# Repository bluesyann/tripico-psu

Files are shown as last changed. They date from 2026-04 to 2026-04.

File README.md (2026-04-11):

<p align="center">
	TriPico PSU Logo
</p>

<h1 align="center">TriPico PSU</h1>

<p align="center">
	
	
	
	
</p>

<p align="center">
	
	
	
</p>

> A 3-channel Raspberry Pi Pico instrument that works as a programmable power supply, bench voltmeter/ammeter, and YAML-driven curve tracer all in one.

---

## ⚡ What Is This?

TriPico PSU is a 3-channel instrument built around a Raspberry Pi Pico and dual INA3221 measurement ICs. It can be configured as:

- **Programmable multi-channel power supply** — independent voltage/current regulation on 3 channels with max power limits
- **Live voltmeter/ammeter front end** — real-time monitoring with interactive desktop GUI and live charts
- **Curve tracer** — automated characterization of transistors, diodes, and components using YAML recipe automation

### Repository Structure

- **[hardware/README.md](hardware/README.md)** — PCB schematic, PCB layout, front-panel design, and wiring integration
- **[firmware/README.md](firmware/README.md)** — Raspberry Pi Pico firmware (MicroPython async control loop)
- **[software/README.md](software/README.md)** — Host computer application (interactive GUI + YAML automation)

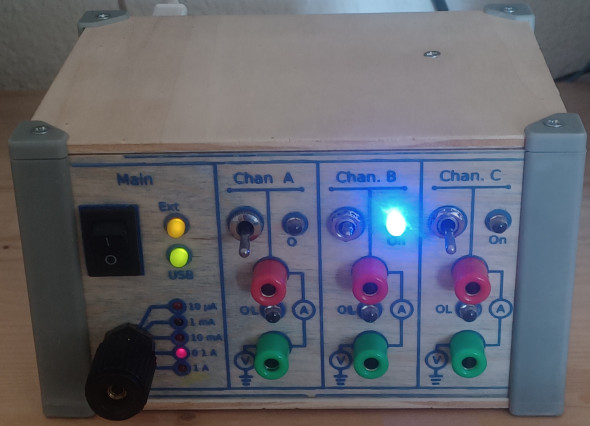
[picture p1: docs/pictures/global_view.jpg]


### Picture Insertion Block: Full Build Overview

Use this block when you have a cleaner hero photo than global_view.jpg.

```md
![TriPico PSU - complete build](docs/pictures/overview_complete_build.jpg)
```

---

## 🎯 How It Works

The Pico firmware regulates 3 channels independently, continuously reads voltage/current through dual INA3221 sensors, and streams measurements over serial at 115200 baud. On the computer side, you have two modes:

- **Interactive GUI mode** — real-time control and monitoring with live voltage/current charts
- **YAML automation mode** — scripted sweeps, static test runs, CSV export, and optional plots

---

## 🚀 Build And Run (Step By Step)

### 1) Build The Hardware

### Picture Insertion Block: Build Steps Collage

Add one image showing PCB + panel + enclosure parts before assembly.

```md
![Hardware build steps](docs/pictures/build_steps_collage.jpg)
```

1. Open the KiCad files and fabricate/assemble the PCB.
2. Build the front panel/enclosure from the provided enclosure assets.
3. Wire the panel elements (switches, relays, connectors, LEDs) to the PCB.

Detailed files and notes are in [hardware/README.md](hardware/README.md).

### 2) Flash The Pico Firmware

### Picture Insertion Block: Pico Flashing

Show your firmware upload workflow or MicroPython file layout.

```md
![Firmware flashing workflow](docs/pictures/pico_firmware_upload.jpg)
```

1. Copy all files from the firmware folder to the Pico:
	 - config.py
	 - device.py
	 - ina3221.py
	 - main.py
2. Reboot the board and verify serial output appears.

Firmware details are in [firmware/README.md](firmware/README.md).

### 3) Set Up The Computer Software

### Picture Insertion Block: Software Setup

Optional terminal screenshot after successful dependency install.

```md
![Host software setup](docs/pictures/software_setup_terminal.jpg)
```

1. Create a Python virtual environment.
2. Install dependencies from software/requirements.txt.
3. Configure software/tripico-psu_config.yaml for your serial port and calibration folder.

Software details are in [software/README.md](software/README.md).

### 4) Use It

### Picture Insertion Block: First Run

Add one screenshot with the GUI connected and channels active.

```md
![First successful run](docs/pictures/first_run_connected_gui.jpg)
```

- GUI mode (interactive bench use):
	- Run software/tripico-psu_gui.py
	- Connect to the Pico
	- Set channel mode (V or mA), setpoint, and max power

- YAML mode (automation and characterization):
	- Run software/tripico-psu_run_yaml.py with one YAML recipe from software/examples
	- Capture sweeps/static runs to CSV and optional plots

---

## 📊 Typical Practical Uses

### Standalone power supply behavior

### Picture Insertion Block: Power Supply Mode

```md
![Power supply mode example](docs/pictures/mode_power_supply.jpg)
```

- Set channels in voltage or current mode
- Apply max-power protection per channel
- Monitor live values and status (regulation/saturation/alerts)

### Digital voltmeter/ammeter style usage

### Picture Insertion Block: Meter Mode

```md
![Voltmeter ammeter mode example](docs/pictures/mode_meter.jpg)
```

- Use one or more channels as sensing points
- Observe time-series voltage/current in the GUI
- Switch measurement range from the front panel selector

### Curve tracer usage

### Picture Insertion Block: Curve Tracer Plot

```md
![Curve tracer example plot](docs/pictures/mode_curve_tracer_plot.jpg)
```

- Define nested sweeps in YAML (for example transistor curves)
- Plot I-V behavior in real time
- Export data for offline analysis

## Example Screens

- GUI examples:
	- [docs/pictures/gui.png](docs/pictures/gui.png)
	- [docs/pictures/gui2.png](docs/pictures/gui2.png)

## Current Status

This repository already contains working code and build assets. Hardware assembly details are intentionally partial and should be completed with your own wiring/BOM documentation as you finalize your build.

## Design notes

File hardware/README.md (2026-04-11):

<p align="center">
  TriPico Hardware Logo
</p>

<h1 align="center">Hardware Build Guide</h1>
<p align="center"><strong>PCB + Front Panel + Wiring Integration</strong></p>

<p align="center">
  
  
  
</p>

# 🏗️ Hardware Build Guide

> PCB design, front-panel enclosure, mechanical integration, and electrical bring-up.

This guide covers the complete hardware design and assembly workflow:

## Picture Insertion Block: Hardware Assembly Overview

```md
![Hardware assembly overview](../docs/pictures/hw_overview_assembly.jpg)
```

- **KiCad project** (complete schematic + PCB layout)
- **Front panel enclosure files** (SVG vector artwork + OpenSCAD 3D extrusion script)

This guide is intentionally conservative where assembly details depend on your specific choices (connectors, wiring gauge, fuse ratings, etc.).

## 📋 What Is In This Folder

## Picture Insertion Block: Repository Hardware Assets

```md
![Hardware files map](../docs/pictures/hw_repo_assets_map.jpg)
```

- kicad/
  - tripico-psu.kicad_sch: electrical schematic
  - tripico-psu.kicad_pcb: PCB layout
  - tripico-psu.kicad_pro and tripico-psu.kicad_prl: project settings

- enclosure/
  - front_panel_inkscape.svg: editable panel design
  - front_panel_polygon.svg: panel path used for extrusion
  - front_panel.scad: OpenSCAD extrusion script

## 🎯 Suggested Physical Architecture

## Picture Insertion Block: Front Panel Layout

```md
![Front panel layout](../docs/pictures/hw_front_panel_layout.jpg)
```

Based on the files and pictures, the build appears to include:

- A main PCB with one Raspberry Pi Pico and analog/power stages
- Front-panel controls and indicators:
  - Main power switch
  - Range selector for current measurement shunts
  - Push-pull channel enable switches (A/B/C)
  - Channel output terminals
  - Status LEDs and safety indication
- External supply input connector

Use the schematic and PCB net labels as the source of truth for wiring.

## 🔨 Build Workflow

### 1) PCB Fabrication And Assembly

### Picture Insertion Block: PCB Render And Assembled Board

```md
![PCB render and assembled board](../docs/pictures/hw_pcb_render_and_real_board.jpg)
```

1. Open kicad/tripico-psu.kicad_pro in KiCad.
2. Run ERC/DRC and inspect any warnings before fabrication.
3. Generate Gerbers and drill files from the PCB editor.
4. Assemble components according to the schematic and footprints.

### 2) Front Panel Fabrication

### Picture Insertion Block: Panel Fabrication

```md
![Panel fabrication process](../docs/pictures/hw_panel_fabrication_steps.jpg)
```

1. Edit enclosure/front_panel_inkscape.svg for labels/hole placement.
2. Use enclosure/front_panel_polygon.svg with OpenSCAD:

```scad
linear_extrude(height = 0.5) import("front_panel_polygon.svg");
```

3. Export for your process (laser/CNC/print) as needed.

### 3) Mechanical Integration

### Picture Insertion Block: Internal Wiring

```md
![Internal wiring and mounting](../docs/pictures/hw_internal_wiring.jpg)
```

1. Mount PCB in enclosure.
2. Mount panel hardware (switches, jacks, LEDs).
3. Route and secure wiring between panel and PCB connectors.

### 4) Electrical Bring-Up

### Picture Insertion Block: Bring-Up Checklist Bench Setup

```md
![Electrical bring up bench setup](../docs/pictures/hw_bringup_bench_setup.jpg)
```

1. Perform continuity checks before power-on.
2. Bring up with current-limited bench supply first.
3. Verify rails, relay behavior, and panel switch detection.
4. Flash firmware and test serial communication with host software.

## ✅ Wiring Checklist (To Complete)

## Picture Insertion Block: Final Wiring Diagram

```md
![Final wiring diagram](../docs/pictures/hw_final_wiring_diagram.jpg)
```

Use this section as your own integration checklist:

- External power input connector pinout: TODO
- Output terminal mapping for channels A/B/C: TODO
- Panel LED wiring and polarity: TODO
- Push-pull switch wiring reference: TODO
- Range selector switch wiring reference: TODO
- Safety relay coil and contact wiring: TODO
- Fuse/protection devices and ratings: TODO

## ⚠️ Safety Notes

- Use an inline fuse on the external supply input.
- Keep high-current traces/wires short and appropriately sized.
- Verify grounding strategy between analog sensing and power paths.
- Confirm enclosure insulation and strain relief before regular use.

## Assets For Documentation

Project image: docs/pictures/global_view.jpg

You can extend this README with BOM, exact connector references, and final wiring photos as you finalize your hardware revision.

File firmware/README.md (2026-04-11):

<p align="center">
  TriPico Firmware Logo
</p>

<h1 align="center">Firmware Guide</h1>
<p align="center"><strong>Raspberry Pi Pico + MicroPython</strong></p>

<p align="center">
  
  
  
</p>

# 🔧 Firmware (Raspberry Pi Pico / MicroPython)

> Complete control loop and measurement streaming for the Raspberry Pi Pico board.

This firmware orchestrates the core device behavior: 3-channel regulation, continuous measurement through INA3221 sensors, safety relay management, and serial communication with the host computer.

## Picture Insertion Block: Firmware Context

```md
![Pico firmware context](../docs/pictures/fw_pico_board_context.jpg)
```

Specifically, it handles:

- 3-channel regulation (voltage or current mode)
- Voltage/current measurements through INA3221 devices
- Safety relay management
- Front-panel switch monitoring
- Serial communication with the host computer

## 📋 Files Overview

- main.py
  - Async entry point and task orchestration
  - Serial RX/TX, regulation loops, state reporting, safety logic

- device.py
  - Hardware initialization (I2C, INA3221, PWM, GPIO, UART)
  - Exposes initialized peripheral objects used by main.py

- config.py
  - Pin mapping and constants
  - PWM settings, range mapping, current limits, safety thresholds

- ina3221.py
  - INA3221 MicroPython driver used for bus voltage and shunt current readings

## 🔌 Hardware Mapping (From Firmware Perspective)

## Picture Insertion Block: Firmware Pinout

```md
![Pico pin mapping used by firmware](../docs/pictures/fw_gpio_mapping_diagram.jpg)
```

- PWM outputs: GPIO 18/17/16 (channels A/B/C)
- INA3221 high-current device on I2C0 (GPIO 8/9)
- INA3221 low-current device on I2C1 (GPIO 2/3)
- Range selector inputs: GPIO 10..14
- Push-pull switch inputs: GPIO 19/20/21
- Safety relays outputs: GPIO 26/27/28
- Safety relay re-enable button: GPIO 22
- UART1 serial: TX GPIO 4, RX GPIO 5

## 🔄 Runtime Architecture

## Picture Insertion Block: Async Task Diagram

```md
![Firmware async task flow](../docs/pictures/fw_async_tasks_flow.jpg)
```

The runtime consists of independent asynchronous tasks that work in parallel without blocking:

- watch_user_panel_state: reads range selector and push-pull switches
- serial_read: parses host commands
- serial_write: sends periodic measurements
- regulator (one per channel): closes control loop
- send_channels_state: emits saturation/regulation states
- safety_relays_control: enforces limits and handles reset button

Each channel dictionary stores setpoints, measurements, state, and hardware references.

## 📡 Host Command Protocol

## Picture Insertion Block: Serial Protocol Cheat Sheet

```md
![Firmware serial command cheat sheet](../docs/pictures/fw_serial_commands_cheatsheet.jpg)
```

The firmware parses line-based commands and supports:

- set sampling <Hz>
- set voffset <V>
- SAFETY RELAYS <0|1>
- USER PANEL STATE
- <channel> v
- <channel> i
- <channel> nc
- <channel> <value>
- <channel> <max_power>w

Where <channel> is a, b, or c.

## Data Stream Format

## Picture Insertion Block: Sample Serial Capture

```md
![Serial data stream capture](../docs/pictures/fw_serial_stream_capture.jpg)
```

The firmware periodically sends one line with:

- elapsed_time_s
- per channel: name i_measured_mA v_measured_V setpoint

Example shape:

```text
12.340 a 5.1 3.30 3.30 b 0.2 1.80 2.00 c 0.0 0.00 0.00
```

Additional event lines are emitted for:

- Range changes
- Channel regulation/saturation state
- Alert conditions
- Push-pull switch changes

## Safety Logic

## Picture Insertion Block: Safety Events

```md
![Safety relay and alert behavior](../docs/pictures/fw_safety_relays_alerts.jpg)
```

Safety relay control checks:

- Max voltage (MAX_VOLTAGE)
- Max current per selected range (MAX_CURRENTS)
- Per-channel max power (from host command)

On violation, relay opens and an Alert event is sent to host.

## Deploy To Pico

## Picture Insertion Block: File Layout On Pico

```md
![Files copied to Pico root](../docs/pictures/fw_files_on_pico_root.jpg)
```

Copy these files to the Pico filesystem root:

- config.py
- device.py
- ina3221.py
- main.py

Then reset the board. main.py starts automatically.

## Tuning Notes

- PID_DT and gain terms in main.py affect regulation stability.
- PWM_FREQ and MAX_PWM_INCREMENT in config.py affect response and smoothness.
- Range selector logic assumes exactly one active (grounded) range pin.

## Debugging Tips

- Open serial logs to verify command parsing and state transitions.
- Check range selector inputs if current reads as None.
- Confirm INA3221 wiring/addressing if channels stop reporting.

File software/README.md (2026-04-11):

<p align="center">
  TriPico Software Logo
</p>

<h1 align="center">Software Guide</h1>
<p align="center"><strong>Host PC Application (GUI + YAML Automation)</strong></p>

<p align="center">
  
  
  
</p>

# 💻 Software (Host Computer)

> Interactive GUI and YAML automation runner that connects over serial to the Pico firmware.

This software provides two complementary modes for interacting with the hardware:

## Picture Insertion Block: Software Overview

```md
![Host software overview](../docs/pictures/sw_overview_gui_and_yaml.jpg)
```

**Two Operating Modes**:

- Interactive GUI mode via tripico-psu_gui.py
- YAML automation mode via tripico-psu_run_yaml.py

## 📚 Files Overview

- tripico-psu_gui.py
	- Desktop GUI for live monitoring and manual channel control
	- Connects over serial to the Pico firmware
	- Displays real-time voltage/current charts and channel states

- tripico-psu_run_yaml.py
	- CLI runner for scripted characterization workflows
	- Validates YAML inputs against validation_schema.yaml
	- Executes sweeps/static runs, writes CSV, optionally saves plots

- serial_functions.py
	- Serial protocol helpers (send commands, parse incoming data)
	- Sweep engine and panel-state checks

- calib_functions.py
	- Loads and applies calibration offsets/gains from external files

- tripico-psu_config.yaml
	- Global host settings (channels, serial device pattern, GUI config, calibration path)

- validation_schema.yaml
	- YAML schema for characterization recipe validation

- examples/
	- Example characterization files for transistor and source testing

## 🐍 Python Environment Setup

## Picture Insertion Block: Dependency Install

```md
![Python environment and dependency install](../docs/pictures/sw_install_dependencies_terminal.jpg)
```

From this folder:

```bash
python -m venv venv
venv\\Scripts\\activate
pip install -r requirements.txt
```

On Linux/macOS:

```bash
python3 -m venv venv
source venv/bin/activate
pip install -r requirements.txt
```

## ⚙️ Configuration

## Picture Insertion Block: Config File Example

```md
![tripico-psu_config.yaml annotated example](../docs/pictures/sw_config_yaml_example.jpg)
```

Edit tripico-psu_config.yaml before running:

- setup.channels: active channels (typically a, b, c)
- setup.device: serial device glob
	- Linux example: /dev/ttyACM*
	- Windows example: COM3
- setup.calibration_folder: path to calibration files
- gui.*: GUI size/colors/sampling/time-window defaults

## 🖥️ Run The GUI (Interactive Mode)

## Picture Insertion Block: GUI Main Window

You can use one of the existing screenshots first, then replace with your own later.

```md
![GUI screenshot](../docs/pictures/gui.png)
```

```bash
python tripico-psu_gui.py
```

Workflow:

1. Select serial port and baudrate.
2. Click Connect.
3. Per channel, set value/unit/max power and click Update.
4. Watch live charts and status fields.

Expected channel status messages include:

- PID Regulation
- Saturation High / Saturation Low
- Alert and push-pull connection state changes

## Picture Insertion Block: GUI Status States

```md
![GUI channel states example](../docs/pictures/sw_gui_channel_states.jpg)
```

## 📈 Run YAML Characterization (Automation Mode)

## Picture Insertion Block: YAML Runner In Terminal

```md
![YAML run from terminal](../docs/pictures/sw_yaml_run_terminal.jpg)
```

```bash
python tripico-psu_run_yaml.py examples/npn_output_characteristics.yaml -device /dev/ttyACM0 -baud 115200
```

Useful options:

- -d / --debug: verbose logging
- --no-prompt: do not wait for Enter between characterizations

The runner will:

1. Load tripico-psu_config.yaml.
2. Validate the input YAML against validation_schema.yaml.
3. Ensure panel/range state is ready.
4. Initialize channels on the Pico.
5. Run sweep/static sequence.
6. Save output CSV when datafile is defined.

## YAML Recipe Structure (Quick Reference)

## Picture Insertion Block: YAML Recipe Annotated

```md
![Annotated characterization YAML](../docs/pictures/sw_yaml_recipe_annotated.jpg)
```

Main keys:

- comment
- caracs: list of characterizations

Per characterization:

- name
- init:
	- range
	- voffset
	- sampling
	- channels: Name, control, initvalue, max_power
- either static or sweep
- optional plots
- optional datafile

Nested sweeps are supported with sweep.sweep for curve tracing.

## Serial Link Expectations

## Picture Insertion Block: Parsed Data And Events

```md
![Data and event parsing overview](../docs/pictures/sw_serial_data_and_events.jpg)
```

- Default baudrate: 115200
- The host expects periodic samples in one line containing timestamp + all channels
- Events (range changes, alerts, state changes) are parsed separately

## Notes

- The software is tightly coupled to firmware command names and channel fields.
- If you rename YAML keys or channel dictionary fields, update GUI/runner/serial helpers together.

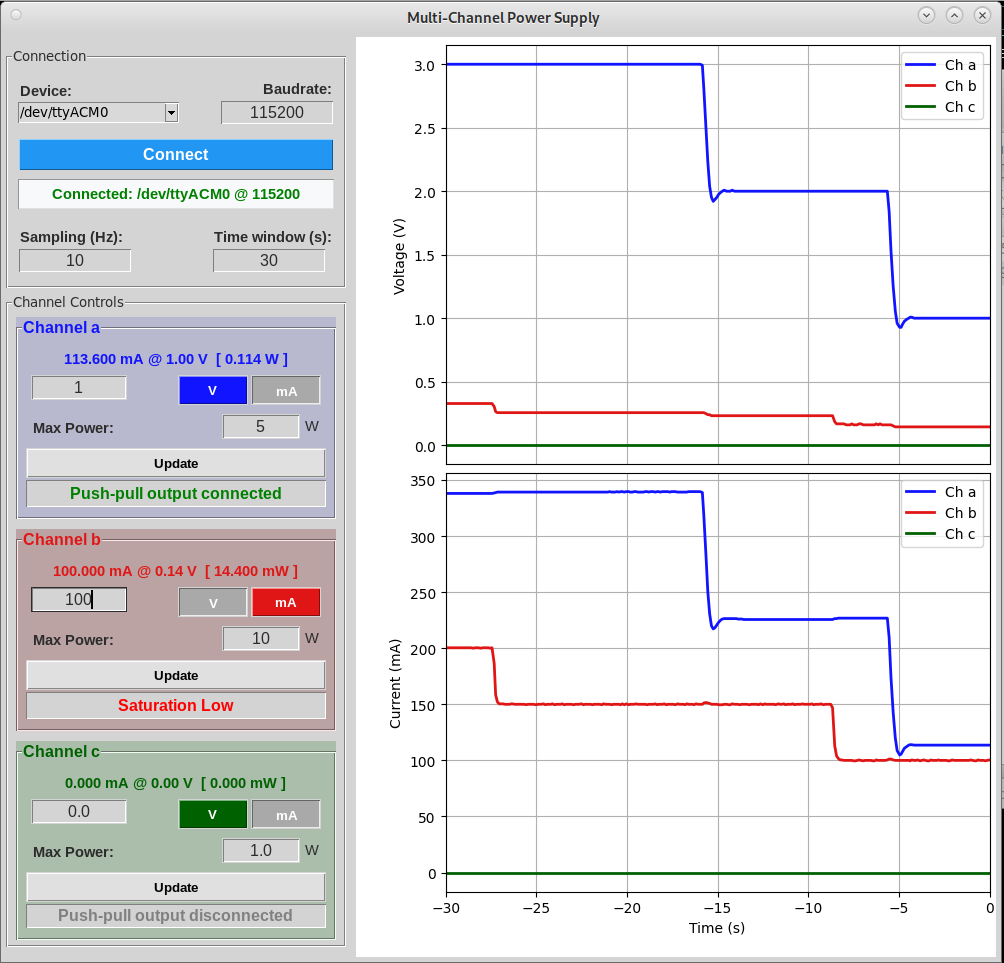
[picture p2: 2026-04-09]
docs/pictures/gui2.png

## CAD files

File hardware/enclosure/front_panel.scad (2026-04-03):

linear_extrude(height = 0.5) import("front_panel_polygon.svg");

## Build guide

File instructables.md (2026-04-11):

# ⚡ TriPico PSU: 3-Channel Raspberry Pi Pico Power Supply, Meter, and Curve Tracer

By <your-name>

> A compact bench instrument that combines a programmable 3-channel power supply, live voltmeter/ammeter interface, and YAML-driven curve tracer — all powered by a Raspberry Pi Pico and dual INA3221 measurement ICs.

Hero image

---

## 🛠️ Supplies

### Electronics

- 1x Raspberry Pi Pico (RP2040)
- 2x INA3221 modules (or equivalent on-board implementation)
- Channel control and output stage components from the KiCad design
- Range selector switch and shunt network
- Safety relays (one per channel)
- Front panel switches, LEDs, and binding posts
- External DC input connector
- Wiring, headers, terminals

### Build Tools

- Soldering iron and solder
- Multimeter
- Wire stripper/cutter
- Small screwdriver set
- PC with USB connection

### Fabrication Tools (Optional)

- PCB fabrication service (Gerbers from KiCad)
- Laser/CNC/3D workflow for panel and enclosure parts

Supplies overview

---

## 🔨 🎯 What You'll Make

TriPico PSU has three regulated channels: A, B, and C.

- Firmware reads voltage and current continuously
- Firmware regulates each channel in voltage mode or current mode
- Safety logic opens relays if voltage/current/power limits are exceeded
- Host app receives live data over serial and plots it
- YAML runner can execute nested sweeps for device characterization

Use cases:

- Standalone power source for test circuits
- Precision monitoring instrument for current/voltage behavior
- Curve tracer for transistor/FET/source characterization

System block diagram

---

## 🔨 Step 2: Build or Order the PCB

Open the hardware design in KiCad:

- hardware/kicad/tripico-psu.kicad_sch
- hardware/kicad/tripico-psu.kicad_pcb

Then:

1. Run ERC/DRC
2. Generate Gerbers and drill files
3. Assemble the board
4. Check continuity before first power-up

Important:

- Keep high-current paths short and thick
- Keep analog sensing paths clean and well-grounded
- Verify there is no short between power rails

PCB view

---

## 🔨 Step 3: Prepare the Front Panel and Enclosure

Panel assets are already included:

- hardware/enclosure/front_panel_inkscape.svg
- hardware/enclosure/front_panel_polygon.svg
- hardware/enclosure/front_panel.scad

Fabrication flow:

1. Adjust labels/hole positions in SVG if needed
2. Generate panel geometry from SVG/SCAD
3. Cut/print panel and mount all controls

Suggested panel elements:

- Main power switch
- Channel A/B/C push-pull toggles
- Ammeter range selector
- Output terminals
- Status LEDs

Front panel build

---

## 🔨 Step 4: Wire the Hardware

Wire panel and board using the KiCad net names as reference.

Minimum wiring checklist:

- Power input and ground
- Channel outputs A/B/C
- Relay control lines
- Push-pull switch inputs
- Range selector lines
- LED indicators

Best practice:

- Route signal and power wiring separately where possible
- Label each harness
- Do a final continuity pass before applying full power

Wiring diagram

---

## 🔨 Step 5: Flash the Pico Firmware

Copy these files from the firmware folder to your Pico:

- config.py
- device.py
- ina3221.py
- main.py

Then reboot.

At startup, firmware:

- Initializes INA3221, GPIO, PWM, UART
- Starts regulation and serial tasks
- Begins streaming measurements

Firmware upload

---

## 🔨 Step 6: Set Up the PC Software

From the software folder:

```bash
python -m venv venv
venv\\Scripts\\activate
pip install -r requirements.txt
```

Edit software/tripico-psu_config.yaml:

- Serial device path
- Channel list
- Calibration folder
- GUI defaults

Software setup

---

## 🔨 Step 7: Run in GUI Mode (Interactive Control)

Start the live application:

```bash
python software/tripico-psu_gui.py
```

Workflow:

1. Connect to serial port
2. Set each channel to V or mA mode
3. Set setpoint and max power
4. Monitor live current/voltage plots

This mode is ideal for bench use and interactive tuning.

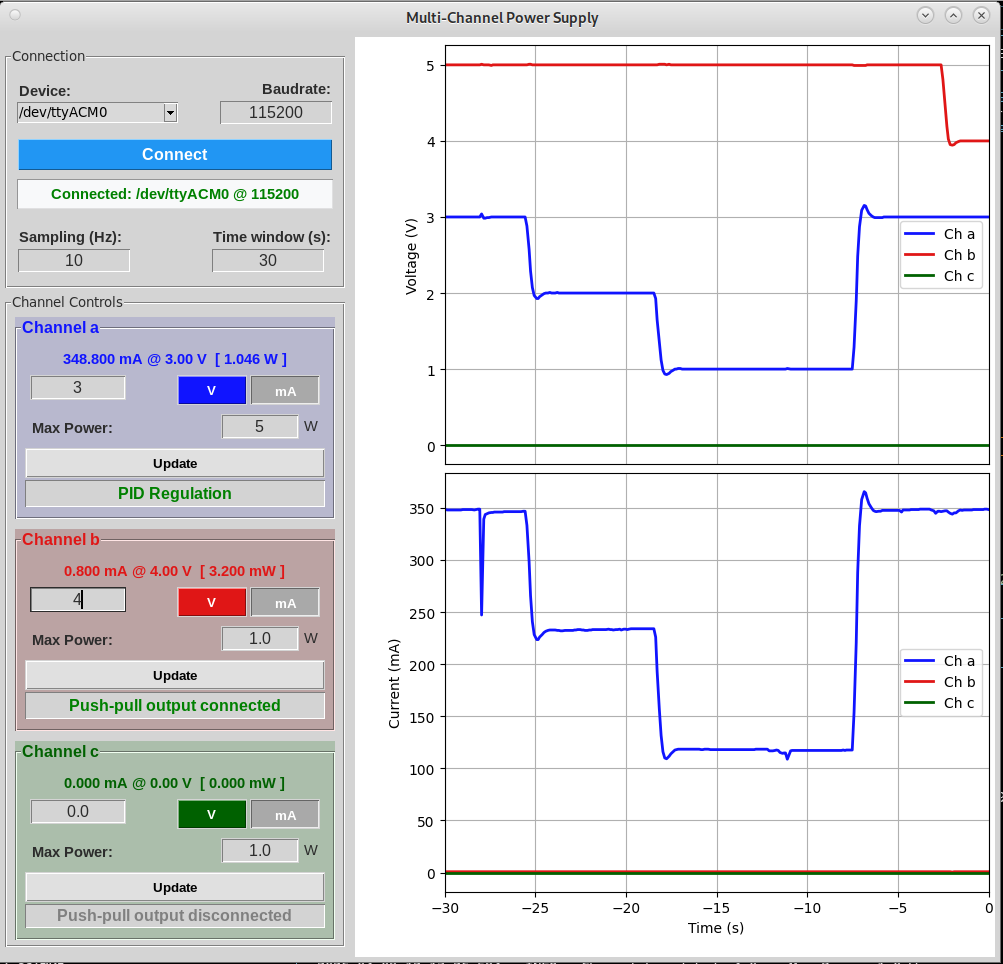
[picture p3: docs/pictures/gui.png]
GUI screenshot


---

## 🔨 Step 8: Run in YAML Automation Mode (Curve Tracer)

Start a characterization run:

```bash
python software/tripico-psu_run_yaml.py software/examples/npn_output_characteristics.yaml -device /dev/ttyACM0 -baud 115200
```

What you get:

- Automatic sweep/static execution
- CSV export
- Optional plot generation

Great for repeatable transistor/FET/source measurements.

Curve tracing output

---

## 🔨 Step 9: Calibration and Safety Checks

Before regular use:

- Verify each ammeter range
- Validate offsets and coefficients in your calibration folder
- Confirm relay cut-off behavior on over-limit conditions
- Test emergency recovery path

Safety reminders:

- Use fused external power input
- Never bypass relay protection
- Keep moisture away from electronics

Safety and calibration

---

## ✨ Results and Practical Use

TriPico PSU now works as:

- A programmable 3-channel supply for prototypes
- A live multi-channel meter
- A compact curve tracer for characterization work

If you build one, share your photos and your wiring/BOM improvements.

Final build

---

## 📁 Project Files

- Main overview: README.md
- Hardware guide: hardware/README.md
- Firmware guide: firmware/README.md
- Software guide: software/README.md

All source files and project assets are in this repository.

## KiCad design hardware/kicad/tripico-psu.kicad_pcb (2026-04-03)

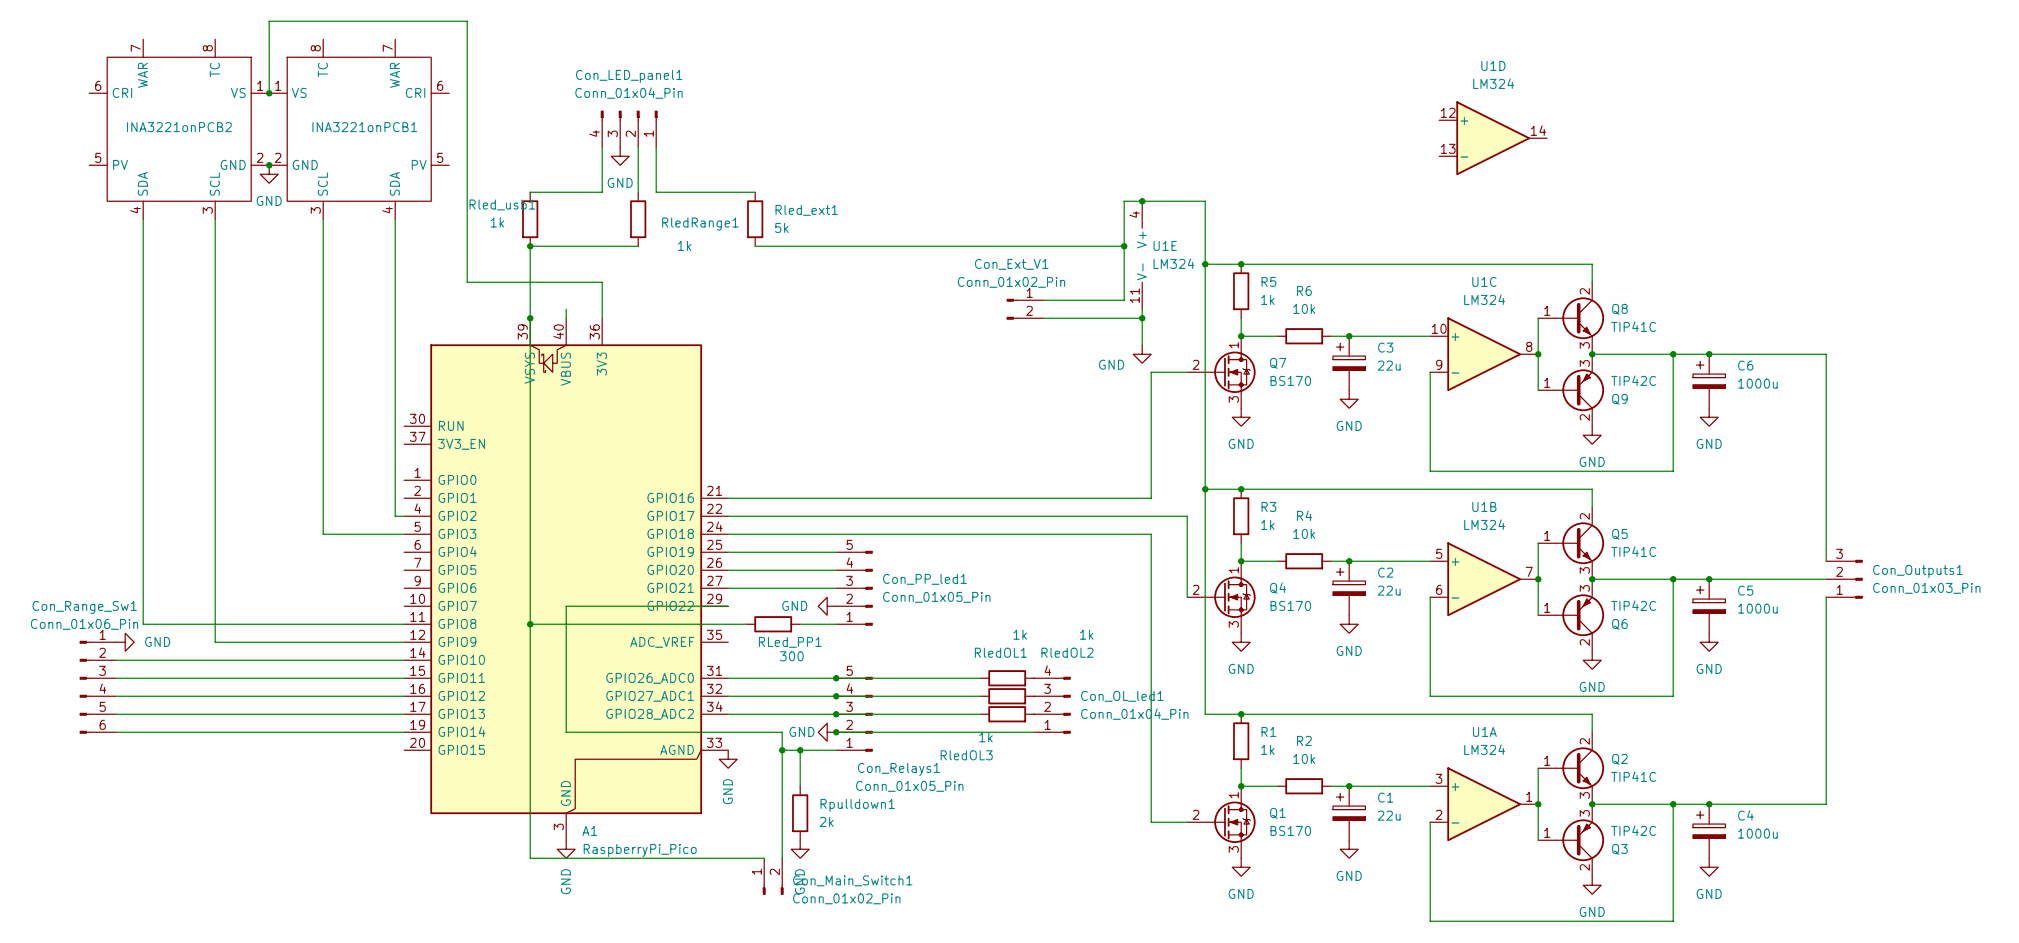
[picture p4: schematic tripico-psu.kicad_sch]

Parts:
A1: RaspberryPi_Pico; RaspberryPi_Pico_THT_NoAntenna
C1, C2, C3: 22u; CP_Radial_D5.0mm_P2.00mm
C4, C5, C6: 1000u; CP_Radial_D16.0mm_P7.50mm
Con_Ext_V1: Conn_01x02_Pin; JST_PH_B2B-PH-K_1x02_P2.00mm_Vertical
Con_LED_panel1: Conn_01x04_Pin; JST_PH_B4B-PH-K_1x04_P2.00mm_Vertical
Con_Main_Switch1: Conn_01x02_Pin; JST_PH_B2B-PH-K_1x02_P2.00mm_Vertical
Con_OL_led1: Conn_01x04_Pin; JST_PH_B4B-PH-K_1x04_P2.00mm_Vertical
Con_Outputs1: Conn_01x03_Pin; JST_PH_B3B-PH-K_1x03_P2.00mm_Vertical
Con_PP_led1: Conn_01x05_Pin; JST_PH_B5B-PH-K_1x05_P2.00mm_Vertical
Con_Range_Sw1: Conn_01x06_Pin; JST_PH_B6B-PH-K_1x06_P2.00mm_Vertical
Con_Relays1: Conn_01x05_Pin; JST_PH_B5B-PH-K_1x05_P2.00mm_Vertical
INA3221onPCB1, INA3221onPCB2: INA3221_on_PCB
Q1, Q4, Q7: BS170; TO-92_Inline
Q2, Q5, Q8: TIP41C; TO-220-3_Vertical
Q3, Q6, Q9: TIP42C; TO-220-3_Vertical
R1, R3, R5: 1k; R_Axial_DIN0207_L6.3mm_D2.5mm_P10.16mm_Horizontal
R2, R4, R6: 10k; R_Axial_DIN0207_L6.3mm_D2.5mm_P10.16mm_Horizontal
RLed_PP1: 300; R_Axial_DIN0207_L6.3mm_D2.5mm_P10.16mm_Horizontal
RledOL1, RledOL2, RledOL3: 1k; R_Axial_DIN0207_L6.3mm_D2.5mm_P10.16mm_Horizontal
RledRange1: 1k; R_Axial_DIN0207_L6.3mm_D2.5mm_P10.16mm_Horizontal
Rled_ext1: 5k; R_Axial_DIN0207_L6.3mm_D2.5mm_P10.16mm_Horizontal
Rled_usb1: 1k; R_Axial_DIN0207_L6.3mm_D2.5mm_P10.16mm_Horizontal
Rpulldown1: 2k; R_Axial_DIN0207_L6.3mm_D2.5mm_P2.54mm_Vertical
U1: LM324; DIP-14_W7.62mm_Socket_LongPads

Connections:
GND: A1.3 (GND), A1.8 (GND), A1.13 (GND), A1.18 (GND), A1.23 (GND), A1.28 (GND), A1.33 (AGND), A1.38 (GND), C1.2, C2.2, C3.2, C4.2, C5.2, C6.2, Con_Ext_V1.2, Con_LED_panel1.3, Con_OL_led1.1, Con_PP_led1.2, Con_Range_Sw1.1, Con_Relays1.2, INA3221onPCB1.2 (GND), INA3221onPCB2.2 (GND), Q1.3 (S), Q3.2 (C), Q4.3 (S), Q6.2 (C), Q7.3 (S), Q9.2 (C), Rpulldown1.2, U1.11 (V-)
unnamed: A1.36 (3V3), INA3221onPCB1.1 (VS), INA3221onPCB2.1 (VS)
unnamed: A1.4 (GPIO2), INA3221onPCB1.4 (SDA)
unnamed: A1.5 (GPIO3), INA3221onPCB1.3 (SCL)
unnamed: A1.11 (GPIO8), INA3221onPCB2.4 (SDA)
unnamed: A1.12 (GPIO9), INA3221onPCB2.3 (SCL)
unnamed: A1.14 (GPIO10), Con_Range_Sw1.2
unnamed: A1.15 (GPIO11), Con_Range_Sw1.3
unnamed: A1.16 (GPIO12), Con_Range_Sw1.4
unnamed: A1.17 (GPIO13), Con_Range_Sw1.5
unnamed: A1.19 (GPIO14), Con_Range_Sw1.6
unnamed: A1.21 (GPIO16), Q7.2 (G)
unnamed: A1.22 (GPIO17), Q4.2 (G)
unnamed: A1.24 (GPIO18), Q1.2 (G)
unnamed: A1.25 (GPIO19), Con_PP_led1.5
unnamed: A1.26 (GPIO20), Con_PP_led1.4
unnamed: A1.27 (GPIO21), Con_PP_led1.3
unnamed: A1.29 (GPIO22), Con_Main_Switch1.2, Con_Relays1.1, Rpulldown1.1
unnamed: A1.31 (GPIO26_ADC0), Con_Relays1.5, RledOL1.1
unnamed: A1.32 (GPIO27_ADC1), Con_Relays1.4, RledOL2.1
unnamed: A1.34 (GPIO28_ADC2), Con_Relays1.3, RledOL3.1
unnamed: A1.39 (VSYS), Con_Main_Switch1.1, RLed_PP1.1, RledRange1.2, Rled_usb1.2
unnamed: Con_Ext_V1.1, Q2.2 (C), Q5.2 (C), Q8.2 (C), R1.1, R3.1, R5.1, Rled_ext1.2, U1.4 (V+)
unnamed: Con_LED_panel1.1, Rled_ext1.1
unnamed: Con_LED_panel1.2, RledRange1.1
unnamed: Con_LED_panel1.4, Rled_usb1.1
unnamed: Con_OL_led1.2, RledOL3.2
unnamed: Con_OL_led1.3, RledOL2.2
unnamed: Con_OL_led1.4, RledOL1.2
unnamed: C4.1, Con_Outputs1.1, Q2.3 (E), Q3.3 (E), U1.2 (-)
unnamed: C5.1, Con_Outputs1.2, Q5.3 (E), Q6.3 (E), U1.6 (-)
unnamed: C6.1, Con_Outputs1.3, Q8.3 (E), Q9.3 (E), U1.9 (-)
unnamed: Con_PP_led1.1, RLed_PP1.2
unnamed: Q1.1 (D), R1.2, R2.1
unnamed: Q2.1 (B), Q3.1 (B), U1.1
unnamed: Q4.1 (D), R3.2, R4.1
unnamed: Q5.1 (B), Q6.1 (B), U1.7
unnamed: Q7.1 (D), R5.2, R6.1
unnamed: Q8.1 (B), Q9.1 (B), U1.8
unnamed: C1.1, R2.2, U1.3 (+)
unnamed: C2.1, R4.2, U1.5 (+)
unnamed: C3.1, R6.2, U1.10 (+)

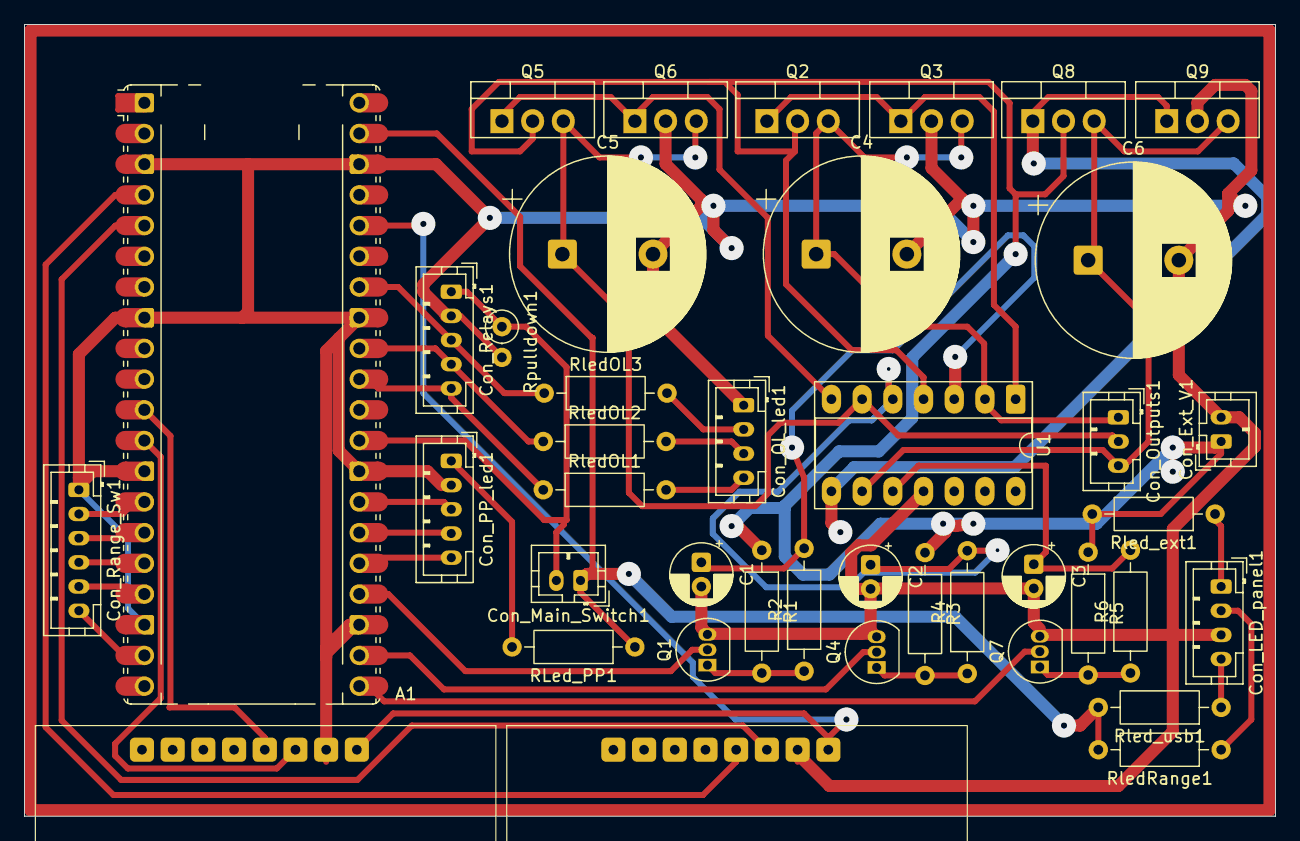
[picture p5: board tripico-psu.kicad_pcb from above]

Board: 2 copper layers, 103.5 x 65.5 mm, 41 parts (0 on the bottom side), 42 nets.

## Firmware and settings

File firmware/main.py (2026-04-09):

# TriPico PSU: 3-Channel Smart Power Supply & Curve Tracer
# RP2040 + INA3221 • Real-time I/V graphs • YAML automation

import asyncio
import time
from device import *

# default sampling frequency
sampling_freq = 1

# Current range switch
range_switch = None

ser = uart1


async def serial_write(channels: list):
    """Send periodic measurement updates from all channels over UART.

    Arguments:
        - channels: list: channel dictionaries to read and report.
    """
    global sampling_freq
    while True:
        # Update all channel measurements
        for ch in channels:
            get_values(ch)

        # Get current time in seconds since the program started
        current_time = time.ticks_ms() / 1000

        # send the values of all channels over UART
        message = f"{current_time} "
        for ch in channels:
            setpoint = ch.get("v_setpoint")
            if setpoint is None:
                setpoint = ch.get("i_setpoint")
            message += f"{ch.get('name')} {ch.get('i_measured')} {ch.get('v_measured')} {setpoint} "
        write_serial(message)
        # print("Sending message over UART:", message.strip())
        await asyncio.sleep_ms(int(1000 / sampling_freq))  # Send message every second


async def adjust_channel(ch: dict, row: list) -> None:
    """Update channel setpoints and modes from a host command.

    Arguments:
        - ch: dict: channel state dictionary to mutate.
        - row: list: parsed command elements (channel, command/value).
    """
    try:
        # Case when push-pull output is to be disconnected
        if row[1] == "nc":
            print(f"Push-pull output not used for channel {ch.get('name')}")

        elif row[1] == "v":
            if ch.get("v_setpoint") is None:
                ch["v_setpoint"] = 0
                ch["i_setpoint"] = None
                print(f"Channel {ch.get('name')} set to voltage regulation mode")

        elif row[1] == "i":
            if ch.get("i_setpoint") is None:
                ch["v_setpoint"] = None
                ch["i_setpoint"] = 0
                print(f"Channel {ch.get('name')} set to current regulation mode")

        elif is_numeric(row[1]):
            if ch.get("v_setpoint") is not None:
                ch["v_setpoint"] = float(row[1])
                print(f"Channel {ch.get('name')}: v_setpoint set to {float(row[1])}")
            else:
                ch["i_setpoint"] = float(row[1])
                print(f"Channel {ch.get('name')}: i_setpoint set to {float(row[1])}")

        elif row[1].endswith("w"):
            mp = row[1][:-1]
            try:
                value = float(mp)
                ch["max_power"] = value * 1000
                print(f"Channel {ch.get('name')}: max_power set to {value}")
            except ValueError:
                print(f"Cannot parse MaxPower value {mp}")

        else:
            print("Invalid parameter for channel adjustment:", row[1])

    except Exception as e:
        print("Error adjusting channel parameters:", e)


def set_voltage_offset(ch: dict, voltage: float) -> None:
    """Configure per-channel voltage offset for measurement correction.

    Arguments:
        - ch: dict: channel state dictionary.
        - voltage: float: offset to subtract from measured voltage.
    """
    try:
        ch["v_offset"] = voltage
        print(f"Voltage offset set to {voltage} V for channel {ch.get('name')}")
    except Exception as e:
        print(f"Error while setting voltage offset for channel {ch.get('name')}: {e}")


def is_numeric(string):
    """Check if a string can be converted to float.

    Arguments:
        - string: str: input to validate.

    Returns:
        - bool: True if numeric, False otherwise.
    """
    try:
        float(string)
        return True
    except ValueError:
        return False


async def serial_read(channels: list):
    """Read and parse commands received from the host via host_serial.

    Arguments:
        - channels: list: channel state dictionaries that can be updated.
    """
    global sampling_freq
    serial_buffer = ""
    while True:
        if ser.any():
            data = ser.read(ser.any())
            if data is not None:
                # Append new data to buffer
                serial_buffer += data.decode("utf-8")

                # Process complete lines (ending with \n or \r)
                while "\n" in serial_buffer:
                    # Split on \n
                    if "\n" in serial_buffer:
                        line, serial_buffer = serial_buffer.split("\n", 1)
                        line = line.strip()

                        # Skip empty lines
                        if not line:
                            break

                        print("Received data over UART:", line)
                        # parse and update setpoints if needed
                        try:
                            processed = False
                            row = line.split(" ")
                            if len(row) == 3:
                                if row[1] == "sampling":
                                    sampling_freq = float(row[2])
                                    print(
                                        f"Updated sampling frequency to {sampling_freq} Hz"
                                    )
                                    processed = True
                                elif row[2] == "STATE":
                                    send_user_panel_state(channels)
                                    processed = True
                                elif row[1] == "voffset":
                                    for ch in channels:
                                        set_voltage_offset(ch, float(row[2]))
                                    processed = True
                                elif row[1] == "RELAYS":
                                    setpoint = int(row[2])
                                    for ch in channels:
                                        print(
                                            f"Setting safety relay of channel {ch.get('name')} to {setpoint}"
                                        )
                                        ch["safety_relay_pin"].value(not setpoint)
                                    processed = True
                            elif len(row) == 2:
                                for ch in channels:
                                    if ch.get("name") == row[0]:
                                        await adjust_channel(ch, row)
                                        processed = True
                                        break

                            if not processed:
                                print("Unknown command: ", line)

                        except Exception as e:
                            print("Error parsing command:", e)
                        break
        await asyncio.sleep_ms(10)  # Check for incoming data every x ms


def send_user_panel_state(channels: list) -> None:
    """Send panel state to the host, including range and push-pull states."""
    global range_switch
    message = f"STATE {range_switch}"

    for ch in channels:
        message += f" {ch.get('pushpull_connected')}"
        if ch.get("pushpull_connected"):
            ch["state"] = ""

    message += f" {sractivate.value()}"
    write_serial(message)


def write_serial(message: str) -> None:
    """Write the provided message to host_serial (USB) and optionally debug UART.

    If using USB CDC mode, this is the host link. UART1 remains available as
    debug channel.
    """
    message += "\n"
    try:
        ser.write(message.encode("utf-8"))
    except Exception:
        pass


async def watch_user_panel_state(channels: list):
    """Monitor hardware switches and update channel states accordingly.

    Arguments:
        - channels: list: channel state dictionaries.
    """
    print("Starting range selector monitoring...")
    global range_switch
    while True:
        # Read the state of the five GPIO pins of the range selector
        n = 0
        selected = None
        for i, _ in enumerate(RANGE_SELECTOR_PINS):
            val = range_selector_pins[i].value()
            n += val
            if val == 0:
                selected = i
        if n == 4 and selected is not None:
            if range_switch is None or selected != range_switch:
                print(f"Selected shunt resistor: {selected}")
                for ch in channels:
                    ch["range"] = selected
                    ch["rshunt"] = SHUNTS[selected]
                range_switch = selected
                write_serial(f"Range {range_switch} selected")
        else:
            print(
                "Invalid shunt resistor selection:",
                [pin.value() for pin in range_selector_pins],
            )
            for ch in channels:
                ch["rshunt"] = None

        # Read push-pull switch states
        for ch in channels:
            swstate = not bool(ch["switch_pin"].value())
            if swstate != ch.get("pushpull_connected"):
                print(f"Push-pull switch set to {swstate} on channel {ch.get('name')}")
                ch["pushpull_connected"] = swstate
                write_serial(f"CH {ch.get('name')} PushPullConnected {swstate}")
        await asyncio.sleep_ms(50)


async def send_channels_state(channels: list):
    """Send current channel internal status (saturation/regulation) to host.

    Arguments:
        - channels: list: channel states to evaluate and report.
    """
    while True:
        for ch in channels:
            if ch.get("safety_relay_on") and ch.get("pushpull_connected"):
                if ch.get("duty") == 0 and ch.get("state") != "Saturation High":
                    print(f"Ch {ch.get('name')} running on saturation High")
                    ch["state"] = "Saturation High"
                    write_serial(f"State {ch.get('name')} Saturation High")

                elif (
                    ch.get("duty") == PWM_RESOLUTION
                    and ch.get("state") != "Saturation Low"
                ):
                    print(f"Ch {ch.get('name')} running on saturation Low")
                    ch["state"] = "Saturation Low"
                    write_serial(f"State {ch.get('name')} Saturation Low")

                elif ch.get("state") != "PID Regulation":
                    if (
                        0.05 * PWM_RESOLUTION
                        < ch.get("duty", 0)
                        < 0.95 * PWM_RESOLUTION
                    ):
                        print(f"Ch {ch.get('name')} regulating")
                        ch["state"] = "PID Regulation"
                        write_serial(f"State {ch.get('name')} PID Regulation")

        await asyncio.sleep_ms(500)


async def regulator(ch: dict):
    """Run PID regulation loop for a given channel.

    Adjusts PWM duty cycle to track setpoint in voltage or current mode.

    Arguments:
        - ch: dict: channel parameters and measured state.

    Returns:
        - None
    """
    se_old = 0  # Stores the error signal for the derivative calculation
    ise = 0  # Integral of the error signal
    while True:
        try:
            i, v = poll_sensors(ch)
        except Exception as e:
            print(f"Error getting i and v on channel {ch.get('name')}: {e}")
            i, v = None, None

        # Skip regulation if sensors return None values
        if v is None or i is None:
            await asyncio.sleep_ms(PID_DT)
            continue

        ch["i_measured"] = i
        ch["v_measured"] = v

        Ki = 1e-4  # integral gain for voltage regulation
        Kp = 5e-3  # proportional gain for voltage regulation
        Kd = 5e-1  # derivative gain for voltage regulation

        se = 0  # error signal
        if ch.get("i_setpoint") is None and ch.get("v_setpoint") is not None:
            se = ch["v_setpoint"] - ch["v_measured"]
        elif ch.get("v_setpoint") is None and ch.get("i_setpoint") is not None:
            """Current regulation with gain scheduling based on setpoint magnitude."""
            if ch["i_setpoint"] < 1e-6:
                ch["i_setpoint"] = 1e-6
            se = 1 - ch.get("i_measured", 0) / ch["i_setpoint"]

        else:
            print("Error: Cant tell wether voltage or current must be regulated.")
            await asyncio.sleep_ms(PID_DT)
            continue

        # PWM Regulation Logic
        ise = se * PID_DT
        dse = (se - se_old) / PID_DT  # Derivative of error
        increment = (
            Kp * se + Kd * dse + Ki * ise
        ) * PWM_RESOLUTION  # Required voltage variation for this iteration

        # Apply the rising time limit
        if abs(increment) > MAX_PWM_INCREMENT:
            increment = MAX_PWM_INCREMENT if increment > 0 else -MAX_PWM_INCREMENT

        ch["duty"] -= int(increment)
        # Clamp duty cycle to valid range when saturation occurs
        if ch["duty"] < 0:
            ch["duty"] = 0
            ise = 0  # Reset the integrator
        elif ch["duty"] > PWM_RESOLUTION:
            ch["duty"] = PWM_RESOLUTION
            ise = 0  # Reset the integrator
        ch["pwm"].duty_u16(ch["duty"])

        # Update old error and damp the integrator
        se_old = se
        ise *= 0.99

        await asyncio.sleep_ms(PID_DT)


def update_load(ch: dict) -> float:
    """
    This function calculate the load on the channel by calculating v/i
    To avoid instability, the load is averaged over several iterations
    Iterations are stored in the array 'Load'
    Argument: channel dictionnary
    Returns: average load
    """
    if ch.get("i_measured") not in (None, 0):
        R = 1e3 * ch.get("v_measured", 0) / ch["i_measured"]
    else:
        R = 1e6  # If no current, assume 1 Mohm

    if len(ch.get("load", [])) > 10:  # Remove the oldest value from the array
        ch["load"].pop(0)

    ch.setdefault("load", []).append(R)
    return sum(ch["load"]) / len(ch["load"])


async def do_nothing():
    """Idle task that keeps the asyncio event loop alive.

    Returns:
        - None
    """
    while True:
        await asyncio.sleep_ms(0)


def poll_sensors(ch: dict) -> tuple:
    """Read voltage/current from INA3221 sensors for the channel.

    Arguments:
        - ch: dict: channel state including range and devices.

    Returns:
        - tuple: (i_mA, v_V) measured current in mA and voltage in V.
    """
    try:
        # Get the data from the High Current device (range=0)
        if ch.get("range") == 0:
            v = ch["high_i_device"].bus_voltage(ch["bus_id"])
            i = 1e3 * ch["high_i_device"].current(ch["bus_id"]) * 0.1
        else:
            v = ch["low_i_device"].bus_voltage(ch["bus_id"])
            i = 1e3 * ch["low_i_device"].current(ch["bus_id"]) * 0.1

        if ch.get("v_offset") is not None:
            v -= ch["v_offset"]

        if ch.get("rshunt") is None:
            print(f"Shunt undefined for channel {ch.get('name')}")
            return (None, v)

        i /= ch["rshunt"]

        # print("Polled values on ch",ch['Name'], i, v)
        # time.sleep(0.5)
        return (i, v)

    except Exception as e:
        print(f"Error polling sensors on channel {ch.get('name')}: {e}")
        ch["safety_relay_on"] = False
        ch["safety_relay_pin"].value(1)
        return (None, None)


def get_values(ch: dict) -> bool:
    """Update channel measured values by polling sensors.

    Arguments:
        - ch: dict: channel state dictionary.

    Returns:
        - bool: True if measurement successful, False otherwise.
    """
    try:
        i, v = poll_sensors(ch)
        ch["i_measured"] = i
        ch["v_measured"] = v
        return True
    except Exception as e:
        print(f"Error getting i and v on channel {ch.get('name')}: {e}")
        return False


async def test_pwm_output():
    """Exercise PWM output over full duty cycle range for debugging.

    Iterates the PWM duty cycle in increments and prints the measured voltage.

    Arguments:
        - None

    Returns:
        - None
    """
    for duty in range(0, PWM_RESOLUTION + 1, 1000):
        pwmc.duty_u16(duty)
        # print(f"Set duty cycle to {duty}/{PWM_RESOLUTION}")
        await asyncio.sleep(0.5)
        # get the voltage after the push pull
        v = inaA.bus_voltage(
            3
        )  # Assuming channel 1 is connected to the push-pull output
        # print(f"Measured voltage: {v} V")
        print(f"{duty}\t{v}")


async def safety_relays_control(channels: list) -> None:
    """Monitor each channel and trigger safety relays on limit violations.

    Checks for over-voltage, over-current, and max power breach, then opens
    the corresponding relay and reports alert state over UART.

    Arguments:
        - channels: list: monitored channel dictionaries.

    Returns:
        - None
    """
    # On startup, activate all the relays
    for ch in channels:
        ch["safety_relay_pin"].value(0)
    last_button_state = True

    while True:
        await asyncio.sleep_ms(100)
        for ch in channels:
            currently_on = ch.get("safety_relay_on", False)
            v = ch.get("v_measured")
            i = ch.get("i_measured")
            message = ""

            if v is not None and v + ch.get("v_offset", 0) > MAX_VOLTAGE:
                ch["safety_relay_on"] = False
                message = "Max voltage reached"

            if ch.get("range") is not None and i is not None:
                if abs(i) > MAX_CURRENTS.get(ch["range"], 0):
                    ch["safety_relay_on"] = False
                    message = "Max current reached"

            if ch.get("max_power") is not None and v is not None and i is not None:
                if abs(i * v) > ch["max_power"]:
                    ch["safety_relay_on"] = False
                    message = f"Max power reached: {int(abs(i*v))} mW"

            if ch.get("safety_relay_on", False) != currently_on:
                ch["safety_relay_pin"].value(1)
                print(
                    f"Ch {ch.get('name')}: SafetyRelayOn from {currently_on} to {ch.get('safety_relay_on')}"
                )
                ch["state"] = "Alert"
                print(message)
                write_serial(f"CH {ch.get('name')} Alert {message}")

        button_state = bool(sractivate.value())
        if button_state and button_state != last_button_state:
            print("User-button pressed, reactivating safety relays")
            for ch in channels:
                ch["safety_relay_on"] = True
                ch.get("safety_relay_pin").value(0)
                write_serial(
                    f"CH {ch.get('name')} PushPullConnected {ch.get('pushpull_connected')}"
                )

        last_button_state = button_state


async def main():
    """Entry point for Pico firmware operation.

    Initializes channel parameters, creates asynchronous tasks for sensor
    reading, regulation control, serial communication and safety checks.

    Arguments:
        - None

    Returns:
        - None
    """
    print("Starting the program...")

    # Define channels parameters
    channels = [
        {
            "name": "a",
            "v_setpoint": 0.0,
            "i_setpoint": None,
            "v_offset": 0.0,
            "max_power": None,
            "v_measured": None,
            "i_measured": None,
            "range": None,
            "rshunt": None,
            "load": [],
            "duty": 0,
            "pushpull_connected": True,
            "state": "",
            "safety_relay_pin": sra,
            "safety_relay_on": True,
            "switch_pin": ppswitcha,
            "pwm": pwma,
            "high_i_device": inaA,
            "low_i_device": inaB,
            "bus_id": 1,
        },
        {
            "name": "b",
            "v_setpoint": 0.0,
            "i_setpoint": None,
            "v_offset": 0.0,
            "max_power": None,
            "v_measured": None,
            "i_measured": None,
            "range": None,
            "rshunt": None,
            "load": [],
            "duty": 0,
            "pushpull_connected": False,
            "state": "",
            "safety_relay_pin": srb,
            "safety_relay_on": True,
            "switch_pin": ppswitchb,
            "pwm": pwmb,
            "high_i_device": inaA,
            "low_i_device": inaB,
            "bus_id": 2,
        },
        {
            "name": "c",
            "v_setpoint": 0.0,
            "i_setpoint": None,
            "v_offset": 0.0,
            "max_power": None,
            "v_measured": None,
            "i_measured": None,
            "range": None,
            "rshunt": None,
            "load": [],
            "duty": 0,
            "pushpull_connected": False,
            "state": "",
            "safety_relay_pin": src,
            "safety_relay_on": True,
            "switch_pin": ppswitchc,
            "pwm": pwmc,
            "high_i_device": inaA,
            "low_i_device": inaB,
            "bus_id": 3,
        },
    ]

    # Start range selector monitoring task
    asyncio.create_task(watch_user_panel_state(channels))

    # Start serial communication task
    asyncio.create_task(serial_write(channels))
    asyncio.create_task(serial_read(channels))
    asyncio.create_task(send_channels_state(channels))

    # Start the regulation tasks
    for ch in channels:
        asyncio.create_task(regulator(ch))

    # Safety relays task
    asyncio.create_task(safety_relays_control(channels))

    # Start do_nothing task to keep the event loop running
    asyncio.create_task(do_nothing())


# Create an Event Loop
loop = asyncio.get_event_loop()
# Create a task to run the main function
loop.create_task(main())
# loop.create_task(test_pwm_output())
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

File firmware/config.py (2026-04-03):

"""
Constants and Pin definitions
"""

PID_DT = 5  # Time in milliseconds between regulator updates


# INA3221 high-current wiring
I2CA_ID = 0
INA_A_SDA_PIN = 8
INA_A_SCL_PIN = 9

# INA3221 low-current wiring
I2CB_ID = 1
INA_B_SDA_PIN = 2
INA_B_SCL_PIN = 3

# I2C Frequency
F = 400000

# PWM definitions
PWM_FREQ = 100000  # PWM frequency in Hz
PWM_RESOLUTION = 65535  # PWM resolution (e.g., 16-bit resolution)

PWM_PIN_CHA = 18  # PWM output for the first channel
PWM_PIN_CHB = 17  # PWM output for the second channel
PWM_PIN_CHC = 16  # PWM output for the third channel

# Regulation parameters
MAX_PWM_INCREMENT = 1000  # Set a limit to the power output rising time

# Range selector pins
RANGE_SELECTOR_PINS = [
    10,
    11,
    12,
    13,
    14,
]  # for 0.1, 1, 10, 100, 1k ohm shunt resistors respectively

# Gross shunt resistor values, common for all channels
SHUNTS = {0: 0.1, 1: 1, 2: 10, 3: 100, 4: 1000}

# Max current per ammeter range in milliamps
MAX_CURRENTS = {0: 1e4, 1: 1e3, 2: 1e2, 3: 1e1, 4: 1e0}

# Max votage before switching a safety relay
MAX_VOLTAGE = 20

# Push-pull output switches status input
PP_SWITCH_CHA = 19
PP_SWITCH_CHB = 20
PP_SWITCH_CHC = 21

# Safety relays control pins
SR_PIN_CHA = 26
SR_PIN_CHB = 27
SR_PIN_CHC = 28

# Safety relays reactivation button
SR_ACTIVATE_PIN = 22

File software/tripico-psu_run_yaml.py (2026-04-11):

from pathlib import Path
import yaml
from jsonschema import validate, ValidationError
import pandas as pd
import asyncio

import matplotlib.pyplot as plt

plt.ion()  # Enable interactive mode

import os
import signal


def is_valid_file(parser, arg):
    """Argparse type helper to validate that the provided path exists.

    Arguments:
        - parser: argparse.ArgumentParser: used to report errors.
        - arg: str: path argument from CLI.

    Returns:
        - Path: validated path object.
    """
    if not os.path.isfile(arg):
        parser.error(f"The file {arg} does not exist!")
    else:
        return Path(arg)


import argparse

parser = argparse.ArgumentParser(
    description="Run voltage sweeps or monitor the multichannel Voltage/Current sensing inteface."
)
parser.add_argument(
    "file",
    type=lambda x: is_valid_file(parser, x),
    help="YAML file describing the process.",
)
parser.add_argument(
    "-device",
    type=str,
    default="/dev/ttyACM0",
    help="Path to the Raspberry Pico device.",
)
parser.add_argument(
    "-baud", type=int, default=115200, help="Baud rate for serial communication."
)
parser.add_argument(
    "-d", "--debug", action="store_true", help="Activate debug logging."
)
parser.add_argument(
    "--no-prompt",
    action="store_true",
    help="Don't wait for interactive prompt at the end of a characterization",
)
args = parser.parse_args()


import logging
from logging.handlers import RotatingFileHandler

level = logging.INFO

# File handler (as you have it)
file_handler = RotatingFileHandler(
    "tripico-psu_run_yaml.log",
    maxBytes=1 * 1024 * 1024,  # 1MB
    backupCount=1,
)
file_handler.setFormatter(logging.Formatter("%(asctime)s - %(levelname)s - %(message)s"))

# Stream handler (for terminal output)
stream_handler = logging.StreamHandler()
stream_handler.setFormatter(logging.Formatter("%(asctime)s - %(levelname)s - %(message)s"))

# Configure logging with both handlers
logging.basicConfig(
    level=level,
    handlers=[file_handler, stream_handler]
)

import serial_functions as serfn
import calib_functions as calfn

PLOT_INTERVAL = 1.0  # seconds


def validate_yaml(data_file: Path, schema_file: Path) -> bool:
    """Validate YAML data against a JSON schema.

    Arguments:
        - data_file: Path: path to YAML file with input configuration.
        - schema_file: Path: path to schema YAML file.

    Returns:
        - bool: True if validation succeeds, False on error.
    """
    logging.info(f"ℹ️ Checking if {data_file} has a valid schema")

    # Load YAML files
    with open(data_file) as f:
        data = yaml.safe_load(f)
    with open(schema_file) as f:
        schema = yaml.safe_load(f)

    try:
        validate(instance=data, schema=schema)
        logging.info("✓ Valid YAML!")
        return True
    except ValidationError as e:
        logging.error(f"✗ Validation failed: {e.message}")
        return False


def create_channels(config: dict) -> list:
    """Create channel data containers from setup configuration."""
    channel_names = config.get("setup", {}).get("channels", [])
    default_setpoint = config.get("setup", {}).get("setpoint", 0)
    default_max_power = config.get("setup", {}).get("max_power", 1)

    channels = []
    for name in channel_names:
        channels.append(
            {
                "name": name,
                "v_data": [],
                "i_data": [],
                "t_data": [],
                "sp_data": [],
                "setpoint": default_setpoint,
                "max_power": default_max_power,
                "i_offset": None,
                "i_coef": 1.0,
            }
        )
    return channels


def get_channel_time_series(channels: list) -> pd.DataFrame:
    """Aggregate channel time-series into a single normalized DataFrame."""
    df = pd.DataFrame()
    if not channels:
        logging.warning("No channels provided to build time series")
        return df

    try:
        for ch in channels:
            chdf = pd.DataFrame(
                list(zip(ch["t_data"], ch["v_data"], ch["i_data"], ch["sp_data"])),
                columns=["t", f"v{ch['name']}", f"i{ch['name']}", f"sp{ch['name']}"],
            )
            df = chdf if df.empty else pd.merge(df, chdf, on="t", how="outer")

        if not df.empty:
            df["t"] = df["t"] - df["t"].min()

        return df
    except Exception as e:
        logging.error("Error while building the dataframe from channels: %s", e)
        return pd.DataFrame()


async def static_run(static: dict) -> None:
    """Hold current setpoints for a fixed duration during a static test.

    Arguments:
        - static: dict: contains `duration` in seconds.

    Returns:
        - None
    """
    duration = static["duration"]
    logging.info(f"⏳ getting data for {duration} seconds...")
    await asyncio.sleep(duration)
    logging.info("✓ Static run completed.")


async def plot_values(channels: list, par: dict, dir: Path):
    """Plot channel quantity over time using a live matplotlib loop.

    Arguments:
        - channels: list: list of channel dictionaries with time series.
        - par: dict: plotting parameters (x, y, color, labels, file, etc.).
        - dir: Path: folder to save plot files when requested.

    Returns:
        - None
    """
    _, ax = plt.subplots()
    logging.info(f"ℹ️ Starting plot for {par}")
    while True:
        try:
            df = get_channel_time_series(channels)

            if len(df) > 5:
                logging.debug(f"Plotting {len(df)} data points")

                ax.clear()  # Clear the axes
                size = par.get("size", 10)  # Default dot size
                if par.get("color") is not None:
                    for y in par["y"]:
                        ax.scatter(
                            df[par["x"]], df[y], label=y, c=df[par["color"]], s=size
                        )
                else:
                    for y in par["y"]:
                        ax.scatter(df[par["x"]], df[y], label=y, s=size)
                ax.set_xlabel(par["xlabel"])
                ax.set_ylabel(par["ylabel"])
                ax.set_title(par["name"])
                ax.grid()
                plt.draw()  # Update the plot
                if "file" in par:
                    plt.savefig(dir / par["file"])  # Save the figure to file
                plt.pause(0.01)  # Small pause to allow rendering
        except Exception as e:
            logging.error(f"Error while drawing chart: {e}")

        await asyncio.sleep(PLOT_INTERVAL)
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

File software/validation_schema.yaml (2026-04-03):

# schema.yml
$schema: "http://json-schema.org/draft-07/schema#"
type: object
required: [comment, caracs]
properties:
  name:
    type: string
    minLength: 1
  comment:
    type: string
    minLength: 1
  calibration_folder:
    type: string
    minLength: 1
  caracs:
    type: array
    minItems: 1
    items:
      type: object
      required: [name, init]
      properties:
        name:
          type: string
          minLength: 1
        datafile:
          type: string
          minLength: 1
          pattern: '^[a-zA-Z0-9_/.-]+$'
        init:
          type: object
          required: [range, voffset, sampling, channels]
          properties:
            range:
              type: integer
              minimum: 0
              maximum: 4
            voffset:
              type: number
              minimum: -10
              maximum: 10
            sampling:
              type: integer
              minimum: 1
              maximum: 1000
            channels:
              type: array
              minItems: 3
              maxItems: 3
              items:
                type: object
                required: [Name, control]
                properties:
                  Name:
                    type: string
                    pattern: "^[a-zA-Z0-9]+$"
                  control:
                    type: string
                    enum: [v, i, nc]
                  max_power:
                    type: number
                    minimum: 0
                    maximum: 10
                  initvalue:
                    type: number
                    minimum: -1000
                    maximum: 1000
        static:
          type: object
          required: [duration]
          properties:
            duration:
              tpye: number
              minimum: 0
              maximum: 1000000
        sweep:
          type: object
          required: [channel, timestep]
          properties:
            channel:
              type: string
              enum: [a, b, c]
            start:
              type: number
              minimum: -1000
              maximum: 1000
            stop:
              type: number
              minimum: -1000
              maximum: 1000
            step:
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
